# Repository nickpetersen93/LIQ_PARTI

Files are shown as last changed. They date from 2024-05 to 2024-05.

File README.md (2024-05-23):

# LIQ PARTI - Lick Instance Quantifier with Poly-Animal RFID Tracking Integration 

## Included in this repository:
  - Arduino code for LIQ PARTI running off an Arduino Mega
  - 3D models for all required 3D-printed components in various file formats (STL, STEP, SHAPR)
  - Step-by-step build instructions and video tutorial can be found on the [Wiki page](https://github.com/nickpetersen93/LIQ_PARTI/wiki/LIQ-PARTI-%E2%80%90-Step-by-Step-Tutorial "LIQ PARTI - Step-by-Step Tutorial")

------------------------------------------------------------------

### Required Arduino Libraries:
  - Adafruit_GFX.h
  - RTClib.h
  - Adafruit_MPR121.h
  - Adafruit_ILI9341.h
  - Adafruit_FT6206.h
  - SparkFun_Qwiic_Rfid.h
  
------------------------------------------------------------------

### Publication Link: TBD

## Abstract

LIQ PARTI, an evolution of LIQ HD, is built from commercially available electronic components combined with 3D-printed parts. Each cage is controlled by a single Arduino MEGA microcontroller connected to a real-time clock plus data logging shield (Adafruit), a capacitive touchscreen shield (Adafruit), a 12-channel MPR121 capacitive sensor breakout board (Adafruit), and two 125kHz RFID readers (SparkFun). Like LIQ HD, LIQ PARTI utilizes capacitive touch sensing to measure individual lick events. The metal sipper for each bottle is in contact with conductive copper foil tape that is wired to the MPR121 capacitance sensor breakout board. The two RFID readers lay inside the 3D-printed housing above two small tunnels that the mice must enter to reach each sipper, which allows the device to accurately determine which mouse is actively drinking from each sipper. Both sippers can be used simultaneously without affecting data collection. Date and time are kept with the Adafruit Data Logger Shield, which also writes the cage data to a CSV file on an SD card for downstream analysis. A 2.8” Adafruit Touchscreen Shield is used to display an easy-to-use graphical user interface, allowing the user to change device settings (time, light/dark schedule, sensor sensitivity, metrics to record), mount/eject the SD card, track the total licks at each sipper throughout recordings, and start/stop/pause recordings. The screen will also prompt the user if there are any errors, such as disconnected sensors or SD card.

<p align="center">

</p>

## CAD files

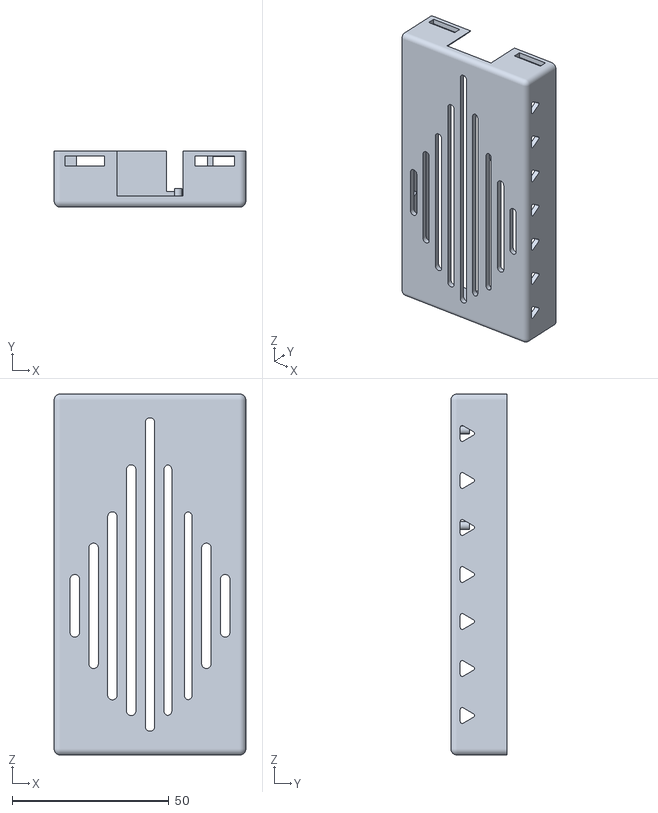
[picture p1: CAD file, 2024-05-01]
LIQ PARTI - 3D Models github/STL/LIQ PARTI - Arduino Case BOTTOM.stl
61.2 x 18.0 x 115.2

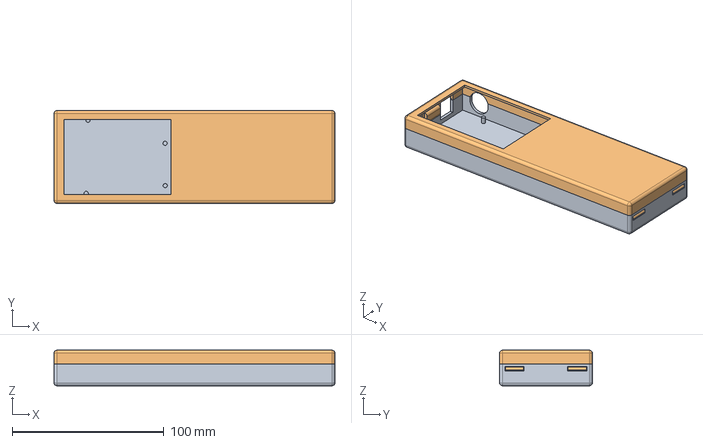
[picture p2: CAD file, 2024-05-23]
RFID_Reader/RFID Reader - 3D Models github/STEP/RFID Reader Case.step
185.2 x 61.2 x 23.5 mm

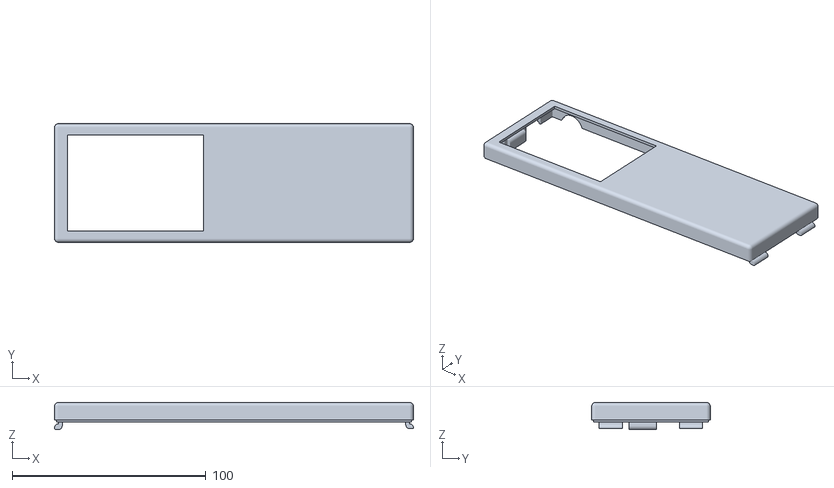
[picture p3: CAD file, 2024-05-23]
RFID_Reader/RFID Reader - 3D Models github/STL/RFID Reader Case - Top.stl
185.2 x 61.2 x 14.0

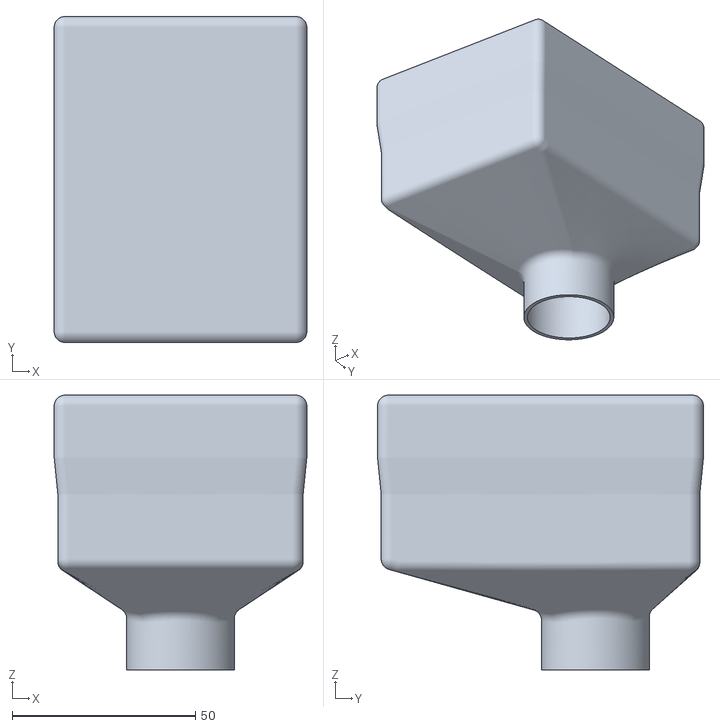
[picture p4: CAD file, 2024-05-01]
LIQ PARTI - 3D Models github/STL/LIQ PARTI - Bottle.stl
69.0 x 89.0 x 75.0

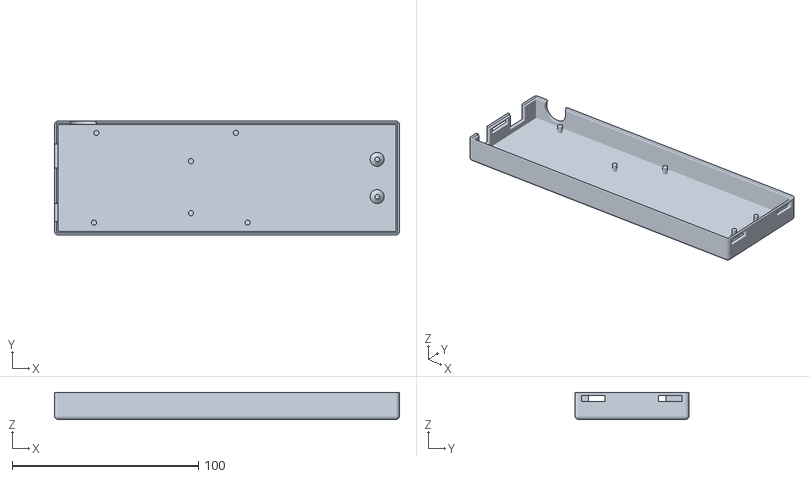
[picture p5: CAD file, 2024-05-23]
RFID_Reader/RFID Reader - 3D Models github/STL/RFID Reader Case - Bottom.stl
185.2 x 61.2 x 14.5

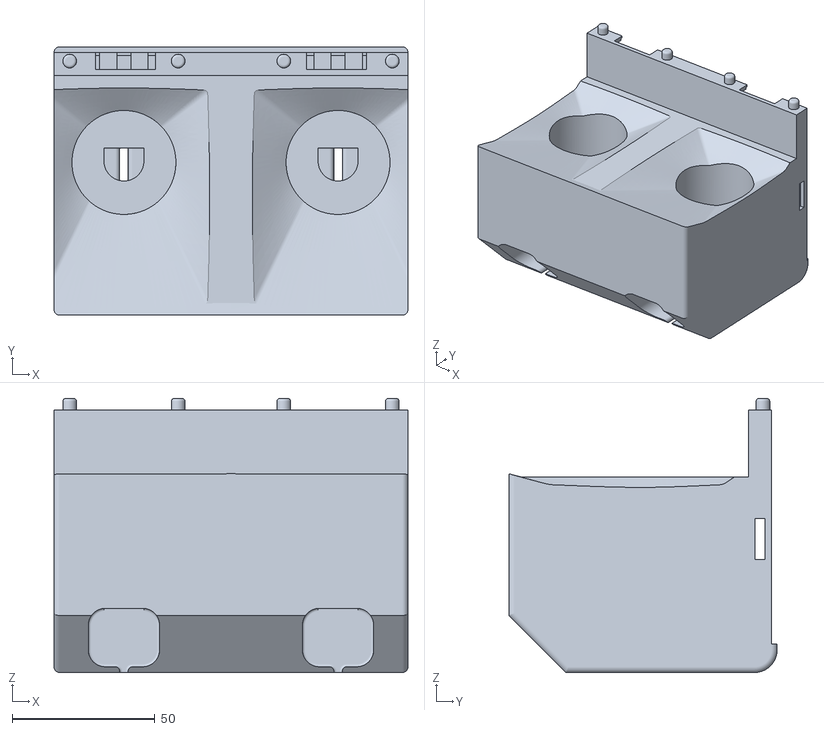
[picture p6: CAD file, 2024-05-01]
LIQ PARTI - 3D Models github/STL/LIQ PARTI - Base.stl
124.0 x 94.0 x 96.0

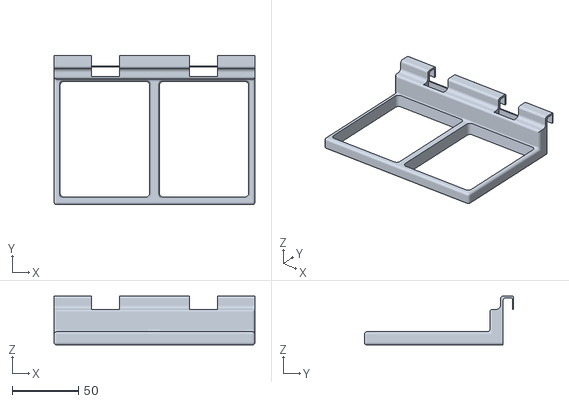
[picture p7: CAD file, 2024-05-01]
LIQ PARTI - 3D Models github/STL/LIQ PARTI - Top Rack.stl
152.0 x 113.0 x 37.0

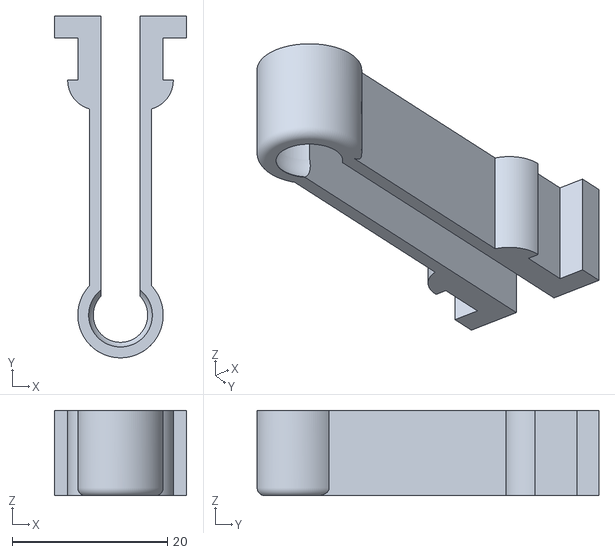
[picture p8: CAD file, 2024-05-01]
LIQ PARTI - 3D Models github/STL/LIQ PARTI - Sipper Clip.stl
17.0 x 44.0 x 11.0

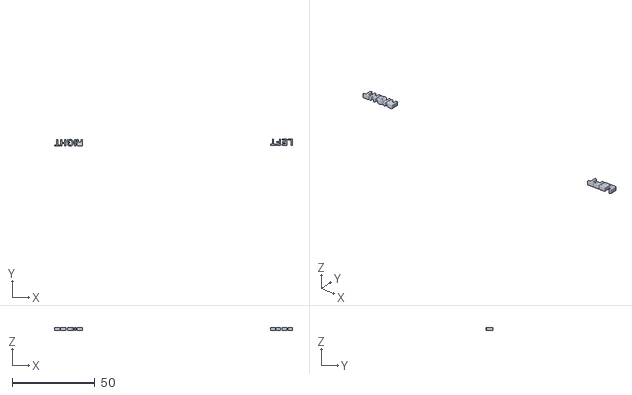
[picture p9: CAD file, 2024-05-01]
LIQ PARTI - 3D Models github/STL/LIQ PARTI - Top Rack TEXT.stl
143.6 x 4.49 x 2.00

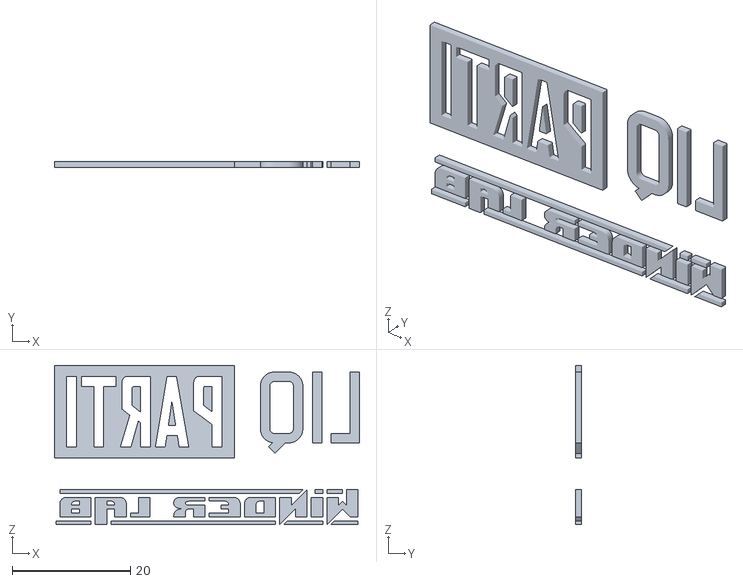
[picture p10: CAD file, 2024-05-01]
LIQ PARTI - 3D Models github/STL/LIQ PARTI - Arduino Case TEXT.stl
51.6 x 1.00 x 27.0

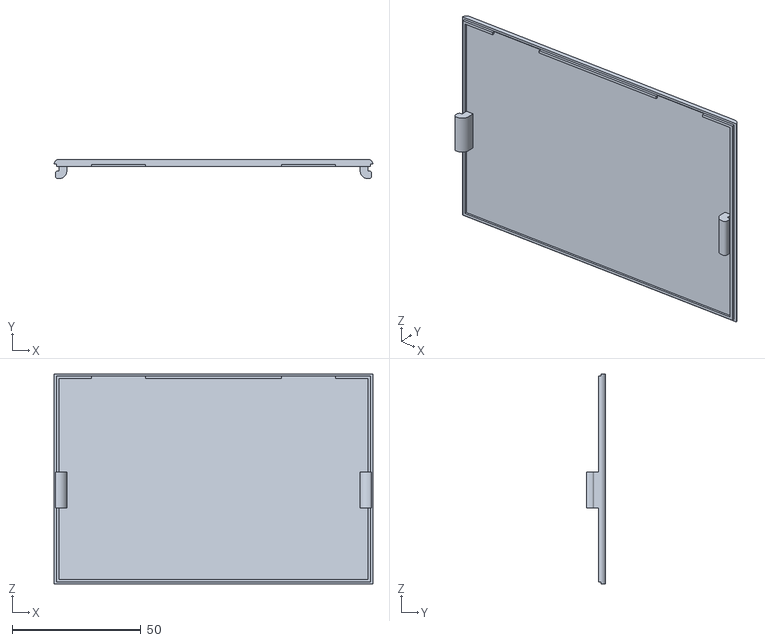
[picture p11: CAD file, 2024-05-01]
LIQ PARTI - 3D Models github/STL/LIQ PARTI - Back Cover.stl
124.0 x 7.50 x 81.6

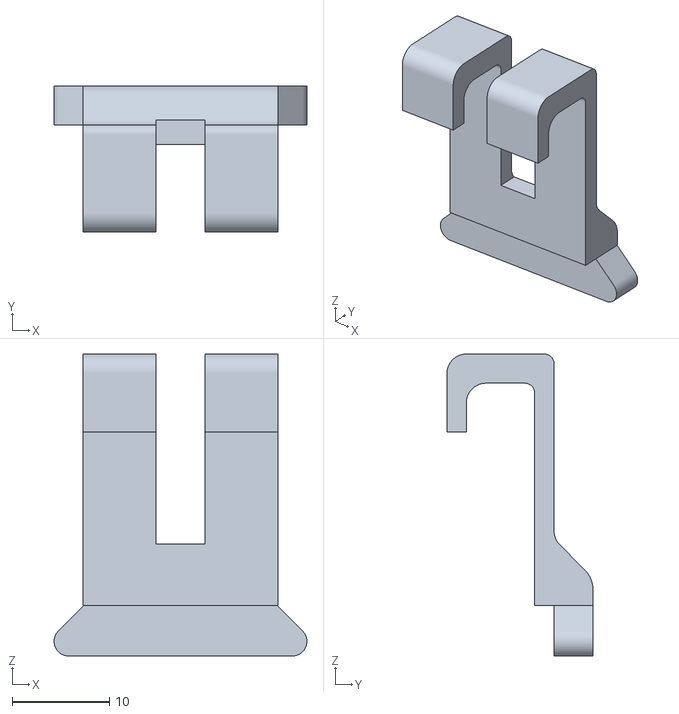
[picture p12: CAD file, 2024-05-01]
LIQ PARTI - 3D Models github/STL/LIQ PARTI - Arduino Case HOOK.stl
26.0 x 15.0 x 31.0

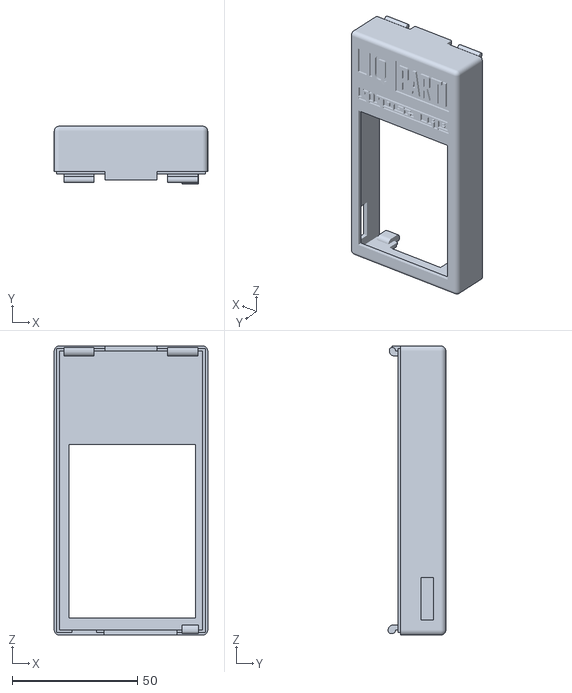
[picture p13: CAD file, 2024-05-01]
LIQ PARTI - 3D Models github/STL/LIQ PARTI - Arduino Case TOP.stl
61.2 x 23.0 x 115.2

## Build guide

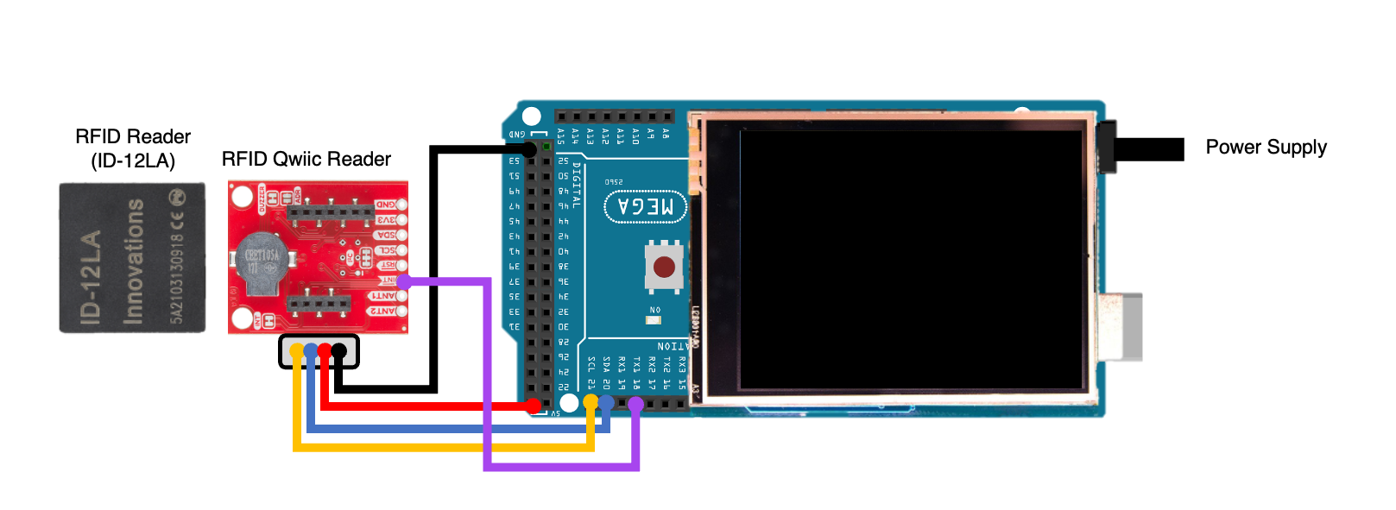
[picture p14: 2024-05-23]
RFID_Reader/RFID reader wiring diagram.png

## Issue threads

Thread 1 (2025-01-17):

Compilation error

tayloryu816, 2025-01-17:
Hi, I’m facing a compilation error while verifying the code, it shows “set_defaults” was not declared in this scope. I wonder how could I fix this.

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

nickpetersen93, 2025-01-17:
It’s looks like it’s missing all of the other code files.  Download the entire “LIQ_PARTI_Arduino_Mega“ and place this folder in your main Arduino folder ( usually Documents>Arduino). Then double click on the “LIQ_PARTI_Arduino_Mega.ino” and it should open all of the files in the folder as separate tabs in the Arduino IDE.

Closed 2025-01-17.

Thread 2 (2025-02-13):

RFID reader 1 not found

tayloryu816, 2025-02-13:
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

Hi, I’m getting an error message saying “RFID reader 1 not found.” I’ve double-checked the wiring and connections, and everything appears correct. I’m not sure how to proceed with troubleshooting at this point. Do you have suggestions on what I should look into next?

Thanks!

nickpetersen93, 2025-02-13:
Hey,
This is likely due to the manufacturer recently changing the default I2C addresses of the RFID readers. Run the "I2C scanner" example code (under File>Examples>Wire>i2c_scanner) in the Arduino IDE with the serial monitor open to look for the I2C addresses of each connected device. The new addresses are 0x13 (left RFID) and 0x14 (right RFID). If this is the case, change this part of the code:

// Default RFID I2C addresses
#define RFID_ADDR1 0x7D
#define RFID_ADDR2 0x7C

to:

// Default RFID I2C addresses
#define RFID_ADDR1 0x13
#define RFID_ADDR2 0x14

tayloryu816, 2025-02-13:
I changed that part of code and now It’s showing a new error that says
“redefinition of ‘Qwiic_Rfid myRfid1’”.

On Thu, Feb 13, 2025 at 15:24 Nick Petersen ***@***.***>
wrote:

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

nickpetersen93, 2025-02-13:
Simply changing the addresses should not cause an error. The code should look like this:

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

tayloryu816, 2025-02-13:
Yes, that's how I changed the code. But the script is read-only mode, so I made a copy; would that be the potential reason that shows the error?

nickpetersen93, 2025-02-13:
I would recommend downloading the "[LIQ_PARTI_Arduino_Mega](https://github.com/nickpetersen93/LIQ_PARTI/tree/main/LIQ_PARTI_Arduino_Mega)" folder, place that folder in your main Arduino folder (usually in Documents), and open it from there. There may have been an issue with making a copy since there are multiple files.

tayloryu816, 2025-02-13:
https://github.com/user-attachments/assets/01fb3569-1c63-4cb4-b088-1ed50f363182

It works now, thank you very much!

So sorry for keeping asking questions, but I also tested the scanner, and I think there’s something wrong with it.

nickpetersen93, 2025-02-14:
Great! It's probably the same issue - go ahead and make the same changes to that code and see if that fixes it.

tayloryu816, 2025-02-20:
The scanner works now! Thank you so much for your help.

I therefore attempted to mimic the mouse-licking motions using my hand. Although the LED on the MPR121 board illuminated (most of the time) when I touched the cables, not every simulated lick was detected.

https://github.com/user-attachments/assets/cd4a7d88-0eb3-4c0f-a5a3-eaf5bc411824

Beimnet-Kassaye, 2025-06-23:
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

Hey, the arduino record lick bouts, which it recognizes as three licks/touches per second. A single touch will not be recorded.

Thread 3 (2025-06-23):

RFID1 reads phantom tags continuously

Beimnet-Kassaye, 2025-06-23:
My LIQ PARTI works beautifully for a few minutes (~6 mins). Then, it starts to malfunction. RFID1 starts to continuously read a false tag (nonexistent tag). After that, all recordings from both RFID readers are non-existent tags that keep on changing every time there is a scan. After  some time, the Arduino board looses connection and it reads RFID1 not found. I have tried changing all components but the problem persists.

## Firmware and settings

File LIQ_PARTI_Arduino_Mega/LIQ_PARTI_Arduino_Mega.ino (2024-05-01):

//#define DEBUG_LIQ //uncomment to turn on debug mode, prints info to Serial Monitor
//#define DEBUG_RFID //uncomment to turn on debug mode, prints info to Serial Monitor
//#define DEBUG_MPR121 //uncomment to turn on debug mode, prints info to Serial Monitor
//#define DEBUG_Screen //uncomment to turn on debug mode, prints info to Serial Monitor
//#define DEBUG_System //uncomment to turn on debug mode, prints info to Serial Monitor

/********************************************************
  LIQ PARTI
  Written by Nicholas Petersen
  https://github.com/nickpetersen93/LIQ_PARTI

  January, 2023

  This work includes libraries with the following licensing:
  Adafruit GFX Library - Written by Limor Fried/Ladyada for Adafruit Industries. BSD License
  Adafruit ILI9341 Library - Written by Limor Fried/Ladyada for Adafruit Industries. MIT license. BSD License.
  Adafruit FT6206 Library - Written by Limor Fried/Ladyada for Adafruit Industries. MIT license.
  Adafruit MPR121 Library - Written by Limor Fried/Ladyada for Adafruit Industries. MIT license. BSD License.
  SparkFun Qwiic RFID Library  - Written by SparkFun. MIT license.
  RTCLib Library - Written by JeeLabs. MIT license.

  This work is released under This work is licensed under a Creative Commons Attribution-NonCommercial-ShareAlike 4.0 International License:
  https://creativecommons.org/licenses/by-nc-sa/4.0/legalcode

  Copyright (c) 2023 Nicholas Petersen. Creative Commons BY-NC-SA License. Non-Commercial Use Only.
  Adapter’s License must be a Creative Commons BY-NC-SA or Compatible License.
  All text above must be included in any redistribution. See LICENSE.md for detailed information.

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
  TO THE EXTENT POSSIBLE, IN NO EVENT WILL THE LICENSOR BE LIABLE TO YOU ON ANY LEGAL THEORY (INCLUDING,
  WITHOUT LIMITATION, NEGLIGENCE) OR OTHERWISE FOR ANY DIRECT, SPECIAL, INDIRECT, INCIDENTAL,
  CONSEQUENTIAL, PUNITIVE, EXEMPLARY, OR OTHER LOSSES, COSTS, EXPENSES, OR DAMAGES ARISING OUT OF THIS
  PUBLIC LICENSE OR USE OF THE LICENSED MATERIAL, EVEN IF THE LICENSOR HAS BEEN ADVISED OF THE
  POSSIBILITY OF SUCH LOSSES, COSTS, EXPENSES, OR DAMAGES. WHERE A LIMITATION OF LIABILITY IS NOT
  ALLOWED IN FULL OR IN PART, THIS LIMITATION MAY NOT APPLY TO YOU.

  THE DISCLAIMER OF WARRANTIES AND LIMITATION OF LIABILITY PROVIDED ABOVE SHALL BE INTERPRETED IN A
  MANNER THAT, TO THE EXTENT POSSIBLE, MOST CLOSELY APPROXIMATES AN ABSOLUTE DISCLAIMER AND WAIVER OF
  ALL LIABILITY.


********************************************************/

#include <Adafruit_GFX.h>
#include <SPI.h>
#include <Wire.h>
#include <SD.h>
#include "RTClib.h"
#include "Adafruit_MPR121.h"
#include "SparkFun_Qwiic_Rfid.h"
#include <Adafruit_ILI9341.h>
#include <Adafruit_FT6206.h>
#include <math.h>
#include <Fonts/FreeSans9pt7b.h>
#include <Fonts/FreeSans12pt7b.h>
#include <Fonts/FreeSans18pt7b.h>
#include <Fonts/FreeSansBold9pt7b.h>
#include <Fonts/FreeSansBold12pt7b.h>
#include <Fonts/FreeSansBold18pt7b.h>
#include <Fonts/FreeSansBold24pt7b.h>

#ifdef DEBUG_LIQ
#define DEBUG_LIQ_PRINT(x)     Serial.print (x)
#define DEBUG_LIQ_PRINTDEC(x)     Serial.print (x, DEC)
#define DEBUG_LIQ_PRINTLN(x)  Serial.println (x)
#else
#define DEBUG_LIQ_PRINT(x)
#define DEBUG_LIQ_PRINTDEC(x)
#define DEBUG_LIQ_PRINTLN(x)
#endif

#ifdef DEBUG_RFID
#define DEBUG_RFID_PRINT(x)     Serial.print (x)
#define DEBUG_RFID_PRINTDEC(x)     Serial.print (x, DEC)
#define DEBUG_RFID_PRINTLN(x)  Serial.println (x)
#else
#define DEBUG_RFID_PRINT(x)
#define DEBUG_RFID_PRINTDEC(x)
#define DEBUG_RFID_PRINTLN(x)
#endif

#ifdef DEBUG_MPR121
#define DEBUG_MPR121_PRINT(x)     Serial.print (x)
#define DEBUG_MPR121_PRINTDEC(x)     Serial.print (x, DEC)
#define DEBUG_MPR121_PRINTLN(x)  Serial.println (x)
#else
#define DEBUG_MPR121_PRINT(x)
#define DEBUG_MPR121_PRINTDEC(x)
#define DEBUG_MPR121_PRINTLN(x)
#endif

#ifdef DEBUG_Screen
#define DEBUG_Screen_PRINT(x)     Serial.print (x)
#define DEBUG_Screen_PRINTDEC(x)     Serial.print (x, DEC)
#define DEBUG_Screen_PRINTLN(x)  Serial.println (x)
#else
#define DEBUG_Screen_PRINT(x)
#define DEBUG_Screen_PRINTDEC(x)
#define DEBUG_Screen_PRINTLN(x)
#endif

#ifdef DEBUG_System
#define DEBUG_System_PRINT(x)     Serial.print (x)
#define DEBUG_System_PRINTDEC(x)     Serial.print (x, DEC)
#define DEBUG_System_PRINTLN(x)  Serial.println (x)
#else
#define DEBUG_System_PRINT(x)
#define DEBUG_System_PRINTDEC(x)
#define DEBUG_System_PRINTLN(x)
#endif


// Default RFID I2C addresses
#define RFID_ADDR1 0x7D
#define RFID_ADDR2 0x7C

Qwiic_Rfid myRfid1(RFID_ADDR1);
Qwiic_Rfid myRfid2(RFID_ADDR2);


// The FT6206 uses hardware I2C on the shield
Adafruit_FT6206 ts = Adafruit_FT6206();

// The display also uses hardware SPI, plus #9 & #10
#define TFT_CS 10
#define TFT_DC 9
Adafruit_ILI9341 tft = Adafruit_ILI9341(TFT_CS, TFT_DC);

RTC_PCF8523 rtc; // define the Real Time Clock object
const int chipSelect = 7; // for the data logging shield, changed from digital pin 10
#define redLEDpin 13
DateTime now;

//capacitive touch device
#ifndef _BV
#define _BV(bit) (1 << (bit))
#endif

// You can have up to 4 on one i2c bus but one is enough for testing!
Adafruit_MPR121 cap = Adafruit_MPR121();

// Keeps track of the last pins touched so we know when buttons are 'released'
uint16_t lasttouched1 = 0;
uint16_t currtouched1 = 0;

File logfile; // the logging file
char filename[] = "00000000.CSV";

TS_Point p;
extern uint8_t welcome_logo[];
extern uint8_t main_logo[];
extern uint8_t settings_icon[];
extern uint8_t settings_icon2[];
extern uint8_t PARTI_LOGOLIQ_PARTI_Winder_Lab_Logo[];
extern uint8_t PARTI_LOGOLIQ_PARTI_Logo[];
unsigned long startmillis;
String E_side = "RIGHT";
String display_page = "main";
bool show_time = true;
bool eject_button;
int LOG_COUNTER;
int SYNC_COUNTER;
unsigned long currentMillis;
unsigned long previousMillis;
int syncTime;
int min_now;
int prev_min;
int curr_min;
int hour_now;
bool refresh_page = true;
int timeouts = 0;
bool ok;
int default_lights_on;
int default_lights_off;
int default_touch_threshold;
int default_release_threshold;
int default_LOG_INTERVAL;
int dafault_SYNC_INTERVAL;
bool default_auto_cal;
int default_auto_cal_time;
int default_auto_cal_sec_since_last_lick;
bool auto_cal_flag = true;
unsigned long cal_timer;
String logging[6];
bool log_LN = true;
bool log_LD = true;
bool log_BN = true;
bool log_BD = true;
bool log_BLN = true;
bool log_BLD = true;
bool recording = false;
bool RFIDerrorLEFT;
bool RFIDerrorRIGHT;
bool RFID_lasterrorLEFT;
bool RFID_lasterrorRIGHT;
int tag1_count;
int lasttag1_count;
int tag2_count;
int lasttag2_count;
int notag1_count;
int notag2_count;
String licked_bottle;

const int intPin1 = 18;
const int intPin2 = 19;
String tag1;
String tag2;
String lasttag1;
String lasttag2;

//enough for 1 cage, 2 lickometers
#define sipper_number 2
unsigned long LickDuration[sipper_number];
unsigned long LickNumber[sipper_number];
unsigned long BoutNumber[sipper_number];
float BoutDuration[sipper_number];
float BoutLickNumber[sipper_number];
float BoutLickDuration[sipper_number];
float LickFrequency[sipper_number];
float ILI[sipper_number];
unsigned long Elapsedtime[sipper_number];
unsigned long total_LN[sipper_number];
int lick_bout_countdown[sipper_number];
unsigned long bout_timer[sipper_number];
unsigned long bout_start_timer[sipper_number];
bool in_bout[sipper_number];
bool licking[sipper_number];
unsigned long time_now[sipper_number];
unsigned long last_lick_time[sipper_number];


// how many minutes between grabbing data and logging it.
int LOG_INTERVAL = 1; // IN MINUTES! between entries (reduce to take more/faster data)
// how many milliseconds before writing the logged data permanently to disk
int SYNC_INTERVAL = 10; // IN MINUTES! between calls to flush() - to write data to the card
unsigned long emergency_counter = 60050; //1 minute +50ms

// Typically touch threshold > release threshold for debouncing
// Decrease value to increase sensitivity
int touch_threshold = 35; //default = 12
int release_threshold = 25; //default = 6
int current = 50; //Range of 1-63uA
int debounce = 0; //range 0-7
bool auto_cal = true;
int auto_cal_time = 7;
int auto_cal_sec_since_last_lick = 60;
int bout_cutoff = 1000;

int lights_on = 6; //time of day (24hr time) housing lights turn ON
int lights_off = 18; //time of day (24hr time) houseing lights turn OFF

//==========================================================================================

void setup() {

#ifdef DEBUG_LIQ || DEBUG_MPR121 || DEBUG_RFID || DEBUG_Screen || DEBUG_System
  Serial.begin(115200);
#endif

  pinMode(5, OUTPUT); // set screen brightness pin as output
  analogWrite(5, 255);
  pinMode(intPin1, INPUT_PULLUP);
  pinMode(intPin2, INPUT_PULLUP);

  set_defaults(); //save coded settings as the default settings

  start_display(); //initialize display

  start_rtc(); //iniitialize rtc

  start_rfid(); //iniitialize RFID readers

  WelcomeScreen(); //display welcome screen at startup

  set_brightness(); //set screen brightness depending on light cycle

}

//==========================================================================================

void loop() {

  main_menu_page();

  recording_page();

  pause_page();

  SD_error_page();

  settings_page();

}

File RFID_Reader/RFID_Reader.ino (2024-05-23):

#include <Adafruit_GFX.h>
#include <SPI.h>
#include <Wire.h>
#include <Adafruit_ILI9341.h>
#include <Fonts/FreeSans9pt7b.h>
#include <Fonts/FreeSans12pt7b.h>
#include <Fonts/FreeSans18pt7b.h>
#include <Fonts/FreeSansBold9pt7b.h>
#include <Fonts/FreeSansBold12pt7b.h>
#include <Fonts/FreeSansBold18pt7b.h>
#include <Fonts/FreeSansBold24pt7b.h>

// The display also uses hardware SPI, plus #9 & #10
#define TFT_CS 10
#define TFT_DC 9
Adafruit_ILI9341 tft = Adafruit_ILI9341(TFT_CS, TFT_DC);

#include "SparkFun_Qwiic_Rfid.h"
#define RFID_ADDR1 0x7D  // Default I2C address
#define RFID_ADDR2 0x7C  // Default I2C address
Qwiic_Rfid myRfid1(RFID_ADDR1);
Qwiic_Rfid myRfid2(RFID_ADDR2);

const int intPin = 18;

String tag1;
String temp1;
String tag2;
String temp2;

void setup() {
  // Begin I-squared-C
  Wire.begin();
  Serial.begin(115200);
  pinMode(intPin, INPUT_PULLUP);
  tft.begin();
  tft.setRotation(1);
  tft.fillScreen(ILI9341_BLACK);
  tft.setFont(&FreeSansBold24pt7b);
  tft.setTextColor(ILI9341_WHITE);
  NickText_center("Ready to read RFID tags!", 160, 120, 1);


  if (myRfid1.begin())
    Serial.println("Ready to scan some tags!");
  else
    Serial.println("Could not communicate with Qwiic RFID!");
  // Want to clear tags sitting on the Qwiic RFID card?
  myRfid1.clearTags();

  if (myRfid2.begin())
    Serial.println("Ready to scan some tags!");
  else
    Serial.println("Could not communicate with Qwiic RFID!");
  // Want to clear tags sitting on the Qwiic RFID card?
  myRfid2.clearTags();
}

void loop() {

  // If the pin goes low, then a card has been scanned.
  int m = micros();
  if (digitalRead(intPin) == LOW) {
    tag1 = myRfid1.getTag();
    //Serial.println(tag1);
    int m2 = micros() - m;
    tft.fillScreen(ILI9341_BLACK);
    tft.setFont(&FreeSansBold24pt7b);
    NickText_center(tag1, 160, 80, 1);
    tft.setFont(&FreeSansBold12pt7b);
    NickText_center("Microseconds to scan:", 160, 150, 1);
    NickText_center(m2, 160, 180, 1);
    myRfid1.clearTags();
  }

return;

  tag1 = myRfid1.getTag();
  if (tag1 != "000000" && temp1 != "-1-1-1-1-1-1") {
    Serial.print("Tag1 ID: ");
    Serial.println(tag1);
    tft.fillScreen(ILI9341_BLACK);
    NickText_center(tag1, 160, 80, 1);
    myRfid1.clearTags();
  }

  tag2 = myRfid2.getTag();
  //delay(50);
  if (tag2 != "000000" && temp2 != "-1-1-1-1-1-1") {
    Serial.print("Tag2 ID: ");
    Serial.println(tag2);
    tft.fillScreen(ILI9341_BLACK);
    NickText_center(tag2, 160, 180, 1);
    myRfid2.clearTags();
  }


}

//======================================================================================



void NickText_center(String text, int center_x, int center_y, int size) {
  tft.setTextSize(size);
  int16_t x1;
  int16_t y1;
  uint16_t w;
  uint16_t h;
  tft.getTextBounds(text, 0, 320, &x1, &y1, &w, &h);
  int xx = (center_x - 1) - (w / 2);
  int yy = (center_y - 1) + (h / 2);
  tft.setCursor(xx, yy);
  tft.print(text);
}

void NickText_center(int text, int center_x, int center_y, int size) {
  tft.setTextSize(size);
  int16_t x1;
  int16_t y1;
  uint16_t w;
  uint16_t h;
  String text2 = String(text);
  tft.getTextBounds(text2, 0, 320, &x1, &y1, &w, &h);
  int xx = (center_x - 1) - (w / 2);
  int yy = (center_y - 1) + (h / 2);
  tft.setCursor(xx, yy);
  tft.print(text2);
}
